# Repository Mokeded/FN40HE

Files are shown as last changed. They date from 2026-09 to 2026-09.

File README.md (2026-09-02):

# FN40HE

FN40HE is a 40%, Hall-effect mechanical keyboard PCB and firmware project. It
adapts the FN40 layout to magnetic (Hall-effect) switches, giving every key
analog actuation — per-key adjustable actuation points, Rapid Trigger,
SOCD/Null Bind, Dynamic Keystroke, and analog gamepad output — instead of a
fixed mechanical trip point.

## What's in this repository

- **KiCad hardware design** — `FN40HE.kicad_pro`/`.kicad_sch`/`.kicad_pcb`,
  a two-layer PCB with 57 independent Hall-sensor channels multiplexed down
  to an 8-channel ADC scan order, plus `FN40HE-plate.step` for the
  mechanical plate reference. `FN40_Project.pretty`, `lib`, `fp-lib-table`,
  and `sym-lib-table` are the local footprint/symbol libraries needed to
  open the project without external dependencies.
- **Firmware** (`firmware/`) — a [libhmk](https://github.com/libhmk/libhmk)-derived
  build configured for the `fn40he` board target, with prebuilt DFU
  artifacts in `firmware/build/` and full source under `firmware/source/`
  for rebuilding.
- **Manufacturing and assembly data** — `FN40HE-BOM.csv` (bill of
  materials for all assembly variants), `FN40HE-ASSEMBLY.md` (which
  mutually-exclusive switch/sensor positions to populate per variant),
  `FN40HE-sensor-map.csv` and `FN40HE-mux-map.csv` (physical-to-firmware
  key mapping), and `manufacturing/FN40HE-Gerbers-JLCPCB.zip` (bare-board
  fab archive).
- **Verification records** — `FN40HE-DRC.rpt` and `FN40HE-ERC.rpt` (PCB/
  schematic check reports) and `FN40HE-J1-WAIVER.md` (documented DRC
  waiver and inspection requirement for the J1 connector footprint).

See `FN40HE-README.md` for release status, build/flash instructions, and
firmware feature details.

## Assembly variants

The board supports three populate/DNP variants sharing one PCB:
**Universal57** (all 57 sensors populated — the released default),
**SplitSpace**, and **SevenUnit** (alternate bottom-row layouts). See
`FN40HE-ASSEMBLY.md` and the DNP columns in `FN40HE-BOM.csv` before
ordering assembly.

## License

This project incorporates GPLv3-derived hardware design and firmware work.
See `LICENSE`. Retain source, license, and attribution when redistributing
modifications.

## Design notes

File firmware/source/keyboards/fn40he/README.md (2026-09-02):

# FN40HE

FN40HE is a 57-position Hall-effect conversion of the Mokeded FN40 PCB. It uses
the HE60 v2 AT32F405 analog architecture and the libhmk firmware stack.

- MCU: AT32F405RCT7
- Oscillator: 12 MHz HSE
- USB: high-speed (`hs`) through the unified daughterboard connector
- Sensors: 57 x MT9102ET
- Multiplexers: 8 x SN74LV4051A
- PCB: 2 layers, 1.2 mm finished thickness

The default key numbering follows `sensor-map.csv`: firmware key 0 is HE1 and
firmware key 56 is HE57. The unused mux slots are encoded as zero, matching
libhmk's convention.

The firmware includes per-key adjustable actuation, split and continuous Rapid
Trigger, Null Bind/SOCD and distance priority, Dynamic Keystroke, tap-hold,
toggle, macros, four onboard profiles, automatic calibration, analog XInput,
and high-speed polling. See [FEATURES.md](FEATURES.md) for configuration details
and safe initial settings. `Fn + F9` swaps profiles and `Fn + F10` selects the
next profile.

Enter the factory AT32 DFU bootloader by holding the physical BOOT button while
connecting USB, or by using the `SP_BOOT` binding on layer 1.

Run `python setup.py -k fn40he`, then `pio run` to build.

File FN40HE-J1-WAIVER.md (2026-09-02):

# J1 mounting-relief DRC waiver

Date: 2026-08-28  
Scope: J1 only — Molex 781710004 unified-daughterboard connector mounting
reliefs.

## Waived findings

The eight annular-width and eight hole-to-hole findings associated with J1's
mounting-relief geometry are waived for this placement-stage revision. They
are intentional features of the project-local
`J1_MOLEX_781710004_MountingReliefs` footprint and do not represent a changed
electrical connection or a routing defect.

The `MP` mounting/relief pad is tied to GND in both the board and schematic.
The J1 position and footprint geometry match the working MX FN40 reference
board used by this project. The electrical pins remain VBUS, D-, D+, and GND.

## Conditions of this waiver

- Use only the specified Molex 781710004 connector and the current local
  footprint geometry.
- Confirm the relief/drill drawing against the selected PCB fabricator's
  capabilities before release.
- Inspect the connector on the first assembled prototype for fit, retention,
  and daughterboard alignment.
- Verify the unified daughterboard cable orientation before applying power.
- This waiver does not cover clearance, shorts, unconnected nets, USB,
  analog, power, mechanical, or any other DRC category.

The imported 4060 DRC policy globally ignores some hole-related categories;
this record preserves the intended, limited engineering rationale for J1.

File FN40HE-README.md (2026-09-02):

# FN40HE release project

This folder is the compact, portable FN40 Hall-effect keyboard project. Open
`FN40HE.kicad_pro` in KiCad 10.

## Release checks completed on 2026-09-01

- PCB DRC: 0 violations, 0 unconnected pads, 0 footprint errors.
- Schematic ERC: 0 errors and 0 warnings.
- Firmware mapping: all 64 mux channels agree across the PCB, schematic,
  `FN40HE-mux-map.csv`, and the firmware configuration.
- ADC order: A3, A4, A5, A6, A7, C4, C5, B0.
- Firmware clean build: successful with compiler warnings treated as errors.
- Firmware size: 33,452 bytes flash (12.8%) and 14,724 bytes RAM (14.1%).
- JLCPCB Gerber ZIP: archive integrity passed.

The firmware is source/build/mapping ready, but it has not yet been proven on
an assembled FN40HE PCB. The first prototype still needs DFU flashing, USB
enumeration, every-key analog verification, calibration, and functional tests
for Rapid Trigger, SOCD, actuation settings, profiles, and alternate layouts.

## Main files

- `FN40HE.kicad_pro`, `FN40HE.kicad_sch`, `FN40HE.kicad_pcb`: KiCad project.
- `FN40_Project.pretty`, `lib`, `fp-lib-table`, `sym-lib-table`: portable local
  footprint and symbol libraries required by the KiCad project.
- `FN40HE-BOM.csv`: assembly bill of materials.
- `FN40HE-ASSEMBLY.md`: mutually exclusive layout/population guidance.
- `FN40HE-sensor-map.csv`, `FN40HE-mux-map.csv`: physical and firmware maps.
- `FN40HE-J1-WAIVER.md`: inherited connector drilling rationale and first-unit
  inspection requirement.
- `FN40HE-DRC.rpt`, `FN40HE-ERC.rpt`: final electrical check reports.
- `FN40HE-plate.step`: plate/mechanical reference.
- `manufacturing/FN40HE-Gerbers-JLCPCB.zip`: current bare-board upload archive.
- `firmware/build/FN40HE.bin`: normal DFU flashing artifact.
- `firmware/build/FN40HE.hex` and `FN40HE.elf`: alternate/debug artifacts.
- `firmware/source`: complete libhmk-derived source for rebuilding.

## Firmware build and flashing

From `firmware/source`, install PlatformIO, then run:

```sh
python setup.py -k fn40he
pio run
```

The checked-in `platformio.ini` is already configured for `fn40he`. Enter the
AT32 factory DFU bootloader by holding BOOT while connecting USB, then flash
`firmware/build/FN40HE.bin` with a compatible AT32/DFU tool. Do not flash the
first production batch before one assembled prototype has passed the hardware
tests listed above.

## Firmware features and configuration

The firmware includes four profiles, per-key adjustable actuation, split and
continuous Rapid Trigger, Null Bind/SOCD and distance priority, Dynamic
Keystroke, macros, analog gamepad mappings, calibration, and high-speed USB
polling. Use hmkconf after flashing and calibration. The default profile starts
with Rapid Trigger and SOCD disabled.

## Manufacturing notes

The intended board is two-layer FR-4, 1.2 mm finished thickness, and 1 oz outer
copper. Review the J1 reliefs and routed NPTH slots in JLCPCB's CAM viewer. The
J1 geometry is inherited from the working MX FN40 and remains a documented
prototype inspection item.

The design and firmware include GPLv3-derived work. Retain `LICENSE`, source,
and attribution when redistributing modifications.

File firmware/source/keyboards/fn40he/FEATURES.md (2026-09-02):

# FN40HE analog and gaming features

The FN40HE firmware uses libhmk's analog input and advanced-key engine. The
settings are stored in the emulated EEPROM on the AT32F405, so the configurator
does not need to stay open after saving a profile.

Use [hmkconf](https://hmkconf.com/) to configure the features below after the
firmware has been flashed and the keyboard has completed its initial
calibration.

## Onboard profiles

The keyboard provides four onboard profiles. Each profile stores its own
keymap, per-key actuation and Rapid Trigger settings, advanced keys, macros,
gamepad bindings, analog curve, and tick rate.

- `Fn + F9`: swap between the default profile and the last non-default profile.
- `Fn + F10`: advance to the next profile.

The default profile starts with Rapid Trigger and SOCD disabled. This avoids
surprising key behavior before the Hall sensors have been tested and calibrated.

The first boot of this feature build resets settings written by the earlier
32-advanced-key FN40 firmware because the persistent profile layout is larger.
Subsequent updates using the same layout preserve the onboard settings normally.

## Adjustable actuation

Every Hall-effect key has an independent actuation point represented internally
as a normalized value from 0 to 255 over its calibrated travel. The default is
128, or approximately the middle of the measured travel. Use the live analog
view in hmkconf to tune actuation after the switches have been installed.

## Rapid Trigger

Rapid Trigger can be enabled per key. Press and release sensitivity can share
one value or use separate values. Continuous mode keeps Rapid Trigger active
until the key returns to its calibrated rest position.

For a first hardware test, begin with a conservative sensitivity and enable it
only on movement keys. Extremely small values can amplify sensor noise or
mechanical wobble, especially before every key has reached bottom-out at least
once and established its travel range.

## SOCD and distance priority

Null Bind pairs provide the following simultaneous-key resolution modes:

- last input wins;
- first/primary key wins;
- second/secondary key wins;
- neutral, where both keys are released;
- distance priority, where the more deeply pressed key wins.

Distance priority is the libhmk equivalent of Wooting's Rappy Snappy behavior.
An optional bottom-out threshold can allow both keys once both have passed that
depth. Typical pairs are `A`/`D` and `W`/`S`.

SOCD rules differ between games and tournaments. Configure the behavior that is
permitted for the intended game rather than assuming last-input or distance
priority is universally allowed.

## Dynamic Keystroke and advanced keys

The firmware reserves 57 advanced-key slots per profile, enough for every
physical Hall-effect key. Supported advanced behaviors include:

- Dynamic Keystroke with up to four bindings and actions at press, bottom-out,
  release from bottom-out, and release;
- tap-hold;
- toggle;
- macros;
- Null Bind/SOCD pairs.

Dynamic Keystroke temporarily controls the affected key's press stages itself,
so the firmware suppresses Rapid Trigger for that key while a DKS stroke is in
progress.

## Analog gamepad

Profiles can map keys to XInput buttons, triggers, or joystick directions. The
analog curve, circular or square joystick output, and snappy opposite-axis
behavior are configurable. XInput is disabled by default so the keyboard starts
as a conventional USB keyboard.

## Calibration and polling

The keyboard automatically calibrates the resting sensor values at startup and
learns each key's bottom-out range during use. A full recalibration is also
available through hmkconf.

High-speed polling is enabled by default for the AT32F405 USB high-speed
interface. The firmware can fall back to the lower polling mode through its
global options if compatibility testing requires it.

## Scope compared with Wooting

These features provide comparable input concepts, but this is not Wooting
firmware and does not use Wootility. Physical travel accuracy depends on the
MT9102ET sensors, magnet/switch geometry, calibration, filtering, and noise of
the assembled FN40HE. RGB lighting is not supported by libhmk.

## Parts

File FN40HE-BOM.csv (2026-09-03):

Item | Value | Package | Manufacturer | Manufacturer_Part_Number | Qty_Universal57 | Qty_SplitSpace | DNP_SplitSpace | Qty_SevenUnit | DNP_SevenUnit | References_Universal57 | Notes
1 | SN74LV4051A | TSSOP-16_4.4x5mm_P0.65mm | Texas Instruments | SN74LV4051APWR | 8 | 8 |  | 8 |  | AM1 AM2 AM3 AM4 AM5 AM6 AM7 AM8 | JLC/LCSC C7793; 8:1 analog mux, TSSOP-16
2 | 100n | C_0402_1005Metric | Samsung Electro-Mechanics | CL05B104KO5NNNC | 70 | 68 | C109 C111 | 65 | C97 C99 C101 C103 C107 | C1 C3 C5 C7 C9 C11 C13 C15 C17 C19 C21 C23 C25 C27 C29 C31 C33 C35 C37 C39 C41 C43 C45 C47 C49 C51 C53 C55 C57 C59 C61 C63 C65 C67 C69 C71 C73 C75 C77 C79 C81 C83 C85 C87 C89 C91 C93 C95 C97 C99 C101 C103 C105 C107 C109 C111 C113 C139 C140 C141 C142 C143 C144 C145 C146 C154 C155 C156 C158 C160 | JLC/LCSC C1525 (Basic part); X7R, 16 V, 10%; package C_0402_1005Metric; reconfirm stock before order
3 | 4.7n | C_0402_1005Metric | Murata | GRM1555C1H472JE01D | 57 | 55 | C110 C112 | 52 | C98 C100 C102 C104 C108 | C2 C4 C6 C8 C10 C12 C14 C16 C18 C20 C22 C24 C26 C28 C30 C32 C34 C36 C38 C40 C42 C44 C46 C48 C50 C52 C54 C56 C58 C60 C62 C64 C66 C68 C70 C72 C74 C76 C78 C80 C82 C84 C86 C88 C90 C92 C94 C96 C98 C100 C102 C104 C106 C108 C110 C112 C114 | JLC/LCSC C1518204; C0G, 50 V, 5%; package C_0402_1005Metric; reconfirm stock before order
4 | 2.2u | C_0603_1608Metric | Murata | GRM188R71A225KE15D | 4 | 4 |  | 4 |  | C148 C149 C150 C151 | JLC/LCSC C86018; X7R, 10 V, 10%; package C_0603_1608Metric; reconfirm stock before order
5 | 30p | C_0603_1608Metric | FH (Guangdong Fenghua) | 0603CG300J500NT | 2 | 2 |  | 2 |  | C152 C153 | JLC/LCSC C1658 (Basic part); C0G, 50 V, 5%; package C_0603_1608Metric; reconfirm stock before order
6 | 10u | C_0603_1608Metric | Yageo | CC0603MRX5R5BB106 | 1 | 1 |  | 1 |  | C157 | JLC/LCSC C109454; X5R, 6.3 V, 20%; package C_0603_1608Metric; reconfirm stock before order
7 | 1u | C_0603_1608Metric | FH (Guangdong Fenghua) | 0603B105K160NT | 1 | 1 |  | 1 |  | C159 | JLC/LCSC C93816; X7R, 16 V, 10%; package C_0603_1608Metric; reconfirm stock before order
8 | BSMD0805-050-24V | Fuse_0805_2012Metric | BHFUSE | BSMD0805-050-24V | 1 | 1 |  | 1 |  | F1 | JLC/LCSC C910822; 0.5 A resettable fuse, 0805; reconfirm stock before order
9 | MT9102ET | MT9102ET / key-center footprint | NOVOSENSE | MT9102ET | 57 | 55 | HE55 HE56 | 52 | HE49 HE50 HE51 HE52 HE54 | HE1 HE2 HE3 HE4 HE5 HE6 HE7 HE8 HE9 HE10 HE11 HE12 HE13 HE14 HE15 HE16 HE17 HE18 HE19 HE20 HE21 HE22 HE23 HE24 HE25 HE26 HE27 HE28 HE29 HE30 HE31 HE32 HE33 HE34 HE35 HE36 HE37 HE38 HE39 HE40 HE41 HE42 HE43 HE44 HE45 HE46 HE47 HE48 HE49 HE50 HE51 HE52 HE53 HE54 HE55 HE56 HE57 | Linear Hall-effect sensor; JLC/LCSC C5447698; verify polarity and switch magnet
10 | Unified_Daughterboard_4P | MOLEX_781710004_MountingReliefs | Molex | 781710004 | 1 | 1 |  | 1 |  | J1 | JLC/LCSC C588524; Pico-EZmate 1.20 mm, 4 circuits; confirm mating cable and footprint drawing
11 | 12k | R_0402_1005Metric | UNI-ROYAL | 0402WGF1202TCE | 2 | 2 |  | 2 |  | R3 R4 | JLC/LCSC C25752 (Basic part); 1%, 1/16 W; package R_0402_1005Metric; reconfirm stock before order
12 | TS-1187A-B-A-B | SW_Push_1P1T_XKB_TS-1187A | XKB Industrial Precision | TS-1187A-B-A-B | 2 | 2 |  | 2 |  | SW1 SW2 | JLC/LCSC C318884; momentary tact switch; reconfirm stock before order
13 | USBLC6-2SC6 | SOT-23-6 | STMicroelectronics | USBLC6-2SC6 | 1 | 1 |  | 1 |  | U1 | JLC/LCSC C7519; USB ESD protection; do not substitute a different manufacturer without review
14 | TLV75733PDBV | SOT-23-5 | Texas Instruments | TLV75733PDBVR | 1 | 1 |  | 1 |  | U2 | JLC/LCSC C485517; 3.3 V LDO, SOT-23-5; reconfirm stock before order
15 | XC6206P332MR-G | SOT-23-3 | Torex Semiconductor | XC6206P332MR-G | 1 | 1 |  | 1 |  | U3 | JLC/LCSC C5446; 3.3 V analog LDO, SOT-23-3; reconfirm stock before order
16 | AT32F405RCT7 | LQFP-64_10x10mm_P0.5mm | Artery Technology | AT32F405RCT7 | 1 | 1 |  | 1 |  | U4 | JLC/LCSC C47090415; 216 MHz MCU, LQFP-64; reconfirm stock before order
17 | X322512MSB4SI | Crystal_SMD_3225-4Pin_3.2x2.5mm | Yangxing Tech | X322512MSB4SI | 1 | 1 |  | 1 |  | Y1 | JLC/LCSC C9002; 12 MHz, 20 pF crystal, 3.2 x 2.5 mm, 4 pad; reconfirm stock before order

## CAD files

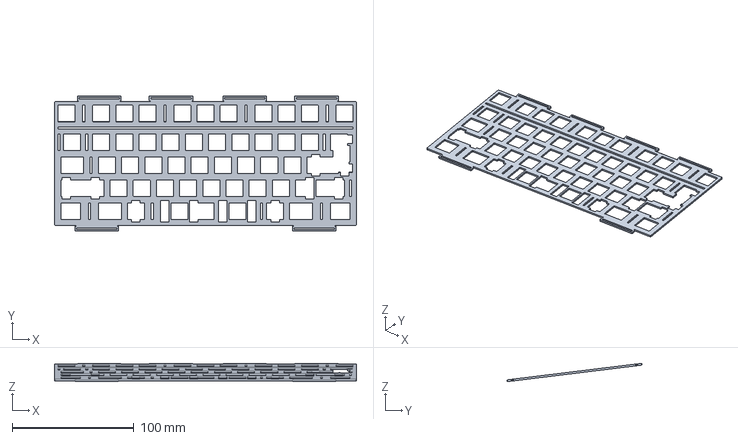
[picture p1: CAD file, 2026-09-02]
FN40HE-plate.step
248.2 x 111.3 x 15.1 mm

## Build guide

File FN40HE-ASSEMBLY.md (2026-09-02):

# Assembly variants

The PCB contains 57 independent Hall-sensor channels. The overlapping bottom
row switch positions are mechanical alternatives; do not install switches or a
plate that attempts to use overlapping options simultaneously.

HE48/HE48A and HE53/HE53A are close alternate-layout pairs. Each pair retains
both switch outlines and both alignment-hole pairs but uses one midpoint Hall
sensor and one capacitor pair, as on HE60. Do not add a second sensor at the
mechanical-only HE48A or HE53A position.

## Universal57 — selected release variant

Populate all PCB components, including all 57 MT9102ET sensors and their local
filter capacitors. Select the physical switch layout with the plate. Unused
sensors remain available for a later layout change. This is the default BOM and
the supplied 57-key firmware configuration. The 2026-08-28 prototype release
package uses this variant; SplitSpace and SevenUnit remain documented future
assembly alternatives and are not the released population set.

## SplitSpace

Use the primary split-space bottom row. Do not populate:

- HE55 / C109 / C110 — alternate SW50 position
- HE56 / C111 / C112 — alternate 7U SW53 position

All other components are populated. Firmware for a permanently assembled
SplitSpace board should replace the two omitted mux entries with zero or ignore
firmware keys 54 and 55.

## SevenUnit

Use the original KLE alternative positions SW50 and SW53. Do not populate the
sensors and filter pairs under primary keys that conflict with the 7U keycap:

- HE49 / C97 / C98 — SW51
- HE50 / C99 / C100 — SW52
- HE51 / C101 / C102 — SW54
- HE52 / C103 / C104 — SW55
- HE54 / C107 / C108 — SW49

Populate HE55 (SW50), HE56 (SW53), and HE57 (SW56). The plate, stabilizer
locations, and keycap clearances must be checked against the original FN40 KLE
before ordering. Firmware for a permanently assembled SevenUnit board should
replace the five omitted mux entries with zero or ignore their firmware keys.

`BOM.csv` contains quantities and DNP reference columns for all three variants.

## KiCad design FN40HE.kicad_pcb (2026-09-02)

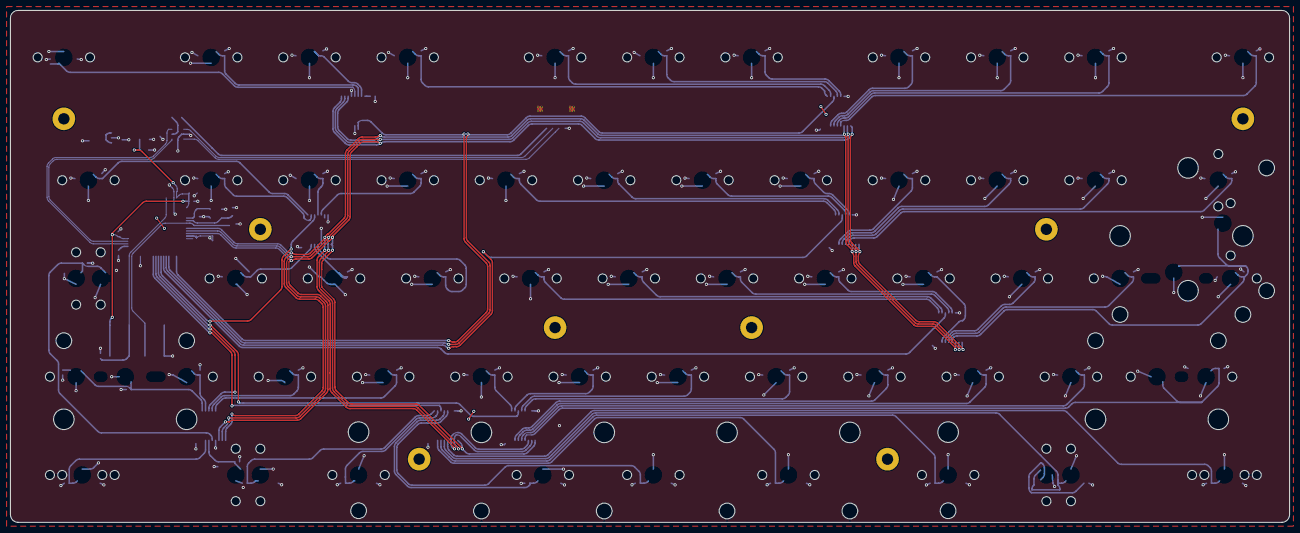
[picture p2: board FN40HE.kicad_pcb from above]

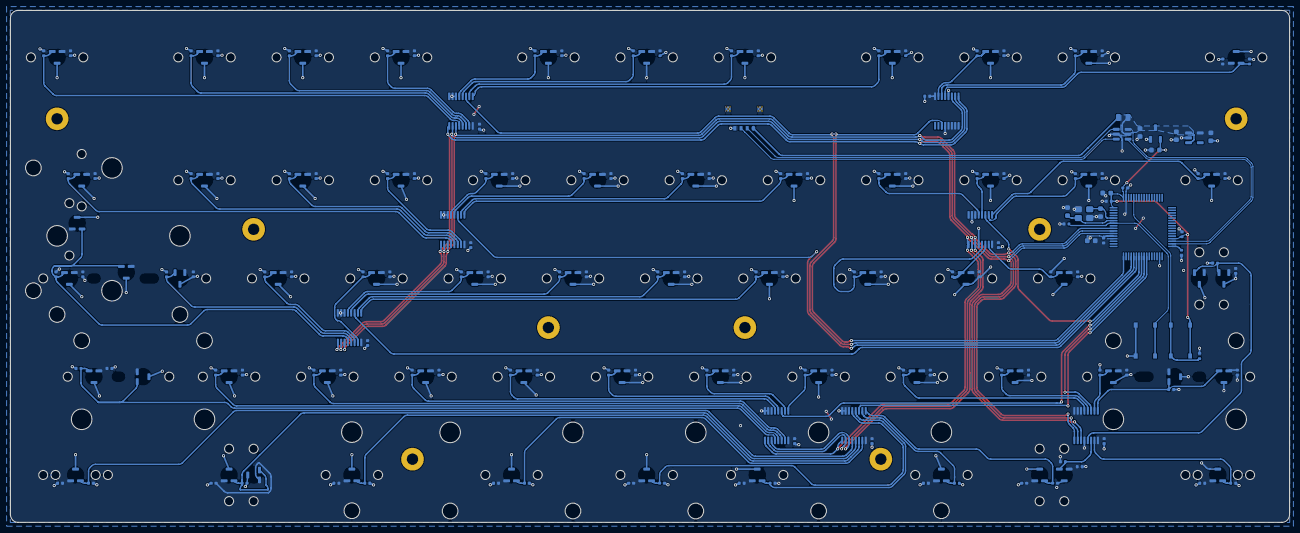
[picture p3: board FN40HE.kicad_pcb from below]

Board: 2 copper layers, 248.0 x 99.2 mm, 234 parts (219 on the bottom side), 82 nets.

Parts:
AM1: SN74LV4051A; AM1_TSSOP-16_4.4x5mm_P0.65mm
AM2: SN74LV4051A; AM2_TSSOP-16_4.4x5mm_P0.65mm
AM3: SN74LV4051A; AM3_TSSOP-16_4.4x5mm_P0.65mm
AM4: SN74LV4051A; AM4_TSSOP-16_4.4x5mm_P0.65mm
AM5: SN74LV4051A; AM5_TSSOP-16_4.4x5mm_P0.65mm
AM6: SN74LV4051A; AM6_TSSOP-16_4.4x5mm_P0.65mm
AM7: SN74LV4051A; AM7_TSSOP-16_4.4x5mm_P0.65mm
AM8: SN74LV4051A; AM8_TSSOP-16_4.4x5mm_P0.65mm
C1: 100n; C1_C_0402_1005Metric
C2: 4.7n; C2_C_0402_1005Metric
C3: 100n; C3_C_0402_1005Metric
C4: 4.7n; C4_C_0402_1005Metric
C5: 100n; C5_C_0402_1005Metric
C6: 4.7n; C6_C_0402_1005Metric
C7: 100n; C7_C_0402_1005Metric
C8: 4.7n; C8_C_0402_1005Metric
C9: 100n; C9_C_0402_1005Metric
C10: 4.7n; C10_C_0402_1005Metric
C11: 100n; C11_C_0402_1005Metric
C12: 4.7n; C12_C_0402_1005Metric
C13: 100n; C13_C_0402_1005Metric
C14: 4.7n; C14_C_0402_1005Metric
C15: 100n; C15_C_0402_1005Metric
C16: 4.7n; C16_C_0402_1005Metric
C17: 100n; C17_C_0402_1005Metric
C18: 4.7n; C18_C_0402_1005Metric
C19: 100n; C19_C_0402_1005Metric
C20: 4.7n; C20_C_0402_1005Metric
C21: 100n; C21_C_0402_1005Metric
C22: 4.7n; C22_C_0402_1005Metric
C23: 100n; C23_C_0402_1005Metric
C24: 4.7n; C24_C_0402_1005Metric
C25: 100n; C25_C_0402_1005Metric
C26: 4.7n; C26_C_0402_1005Metric
C27: 100n; C27_C_0402_1005Metric
C28: 4.7n; C28_C_0402_1005Metric
C29: 100n; C29_C_0402_1005Metric
C30: 4.7n; C30_C_0402_1005Metric
C31: 100n; C31_C_0402_1005Metric
C32: 4.7n; C32_C_0402_1005Metric
C33: 100n; C33_C_0402_1005Metric
C34: 4.7n; C34_C_0402_1005Metric
C35: 100n; C35_C_0402_1005Metric
C36: 4.7n; C36_C_0402_1005Metric
C37: 100n; C37_C_0402_1005Metric
C38: 4.7n; C38_C_0402_1005Metric
C39: 100n; C39_C_0402_1005Metric
C40: 4.7n; C40_C_0402_1005Metric
C41: 100n; C41_C_0402_1005Metric
C42: 4.7n; C42_C_0402_1005Metric
C43: 100n; C43_C_0402_1005Metric
C44: 4.7n; C44_C_0402_1005Metric
C45: 100n; C45_C_0402_1005Metric
C46: 4.7n; C46_C_0402_1005Metric
C47: 100n; C47_C_0402_1005Metric
C48: 4.7n; C48_C_0402_1005Metric
C49: 100n; C49_C_0402_1005Metric
C50: 4.7n; C50_C_0402_1005Metric
C51: 100n; C51_C_0402_1005Metric
C52: 4.7n; C52_C_0402_1005Metric
C53: 100n; C53_C_0402_1005Metric
C54: 4.7n; C54_C_0402_1005Metric
C55: 100n; C55_C_0402_1005Metric
C56: 4.7n; C56_C_0402_1005Metric
C57: 100n; C57_C_0402_1005Metric
C58: 4.7n; C58_C_0402_1005Metric
C59: 100n; C59_C_0402_1005Metric
C60: 4.7n; C60_C_0402_1005Metric
C61: 100n; C61_C_0402_1005Metric
C62: 4.7n; C62_C_0402_1005Metric
C63: 100n; C63_C_0402_1005Metric
C64: 4.7n; C64_C_0402_1005Metric
C65: 100n; C65_C_0402_1005Metric
C66: 4.7n; C66_C_0402_1005Metric
C67: 100n; C67_C_0402_1005Metric
C68: 4.7n; C68_C_0402_1005Metric
C69: 100n; C69_C_0402_1005Metric
C70: 4.7n; C70_C_0402_1005Metric
C71: 100n; C71_C_0402_1005Metric
C72: 4.7n; C72_C_0402_1005Metric
C73: 100n; C73_C_0402_1005Metric
C74: 4.7n; C74_C_0402_1005Metric
C75: 100n; C75_C_0402_1005Metric
C76: 4.7n; C76_C_0402_1005Metric
C77: 100n; C77_C_0402_1005Metric
C78: 4.7n; C78_C_0402_1005Metric
C79: 100n; C79_C_0402_1005Metric
C80: 4.7n; C80_C_0402_1005Metric
C81: 100n; C81_C_0402_1005Metric
C82: 4.7n; C82_C_0402_1005Metric
C83: 100n; C83_C_0402_1005Metric
C84: 4.7n; C84_C_0402_1005Metric
C85: 100n; C85_C_0402_1005Metric
C86: 4.7n; C86_C_0402_1005Metric
C87: 100n; C87_C_0402_1005Metric
C88: 4.7n; C88_C_0402_1005Metric
C89: 100n; C89_C_0402_1005Metric
C90: 4.7n; C90_C_0402_1005Metric
C91: 100n; C91_C_0402_1005Metric
C92: 4.7n; C92_C_0402_1005Metric
C93: 100n; C93_C_0402_1005Metric
C94: 4.7n; C94_C_0402_1005Metric
C95: 100n; C95_C_0402_1005Metric
C96: 4.7n; C96_C_0402_1005Metric
C97: 100n; C97_C_0402_1005Metric
C98: 4.7n; C98_C_0402_1005Metric
C99: 100n; C99_C_0402_1005Metric
C100: 4.7n; C100_C_0402_1005Metric
C101: 100n; C101_C_0402_1005Metric
C102: 4.7n; C102_C_0402_1005Metric
C103: 100n; C103_C_0402_1005Metric
C104: 4.7n; C104_C_0402_1005Metric
C105: 100n; C105_C_0402_1005Metric
C106: 4.7n; C106_C_0402_1005Metric
C107: 100n; C107_C_0402_1005Metric
C108: 4.7n; C108_C_0402_1005Metric
C109: 100n; C109_C_0402_1005Metric
C110: 4.7n; C110_C_0402_1005Metric
C111: 100n; C111_C_0402_1005Metric
C112: 4.7n; C112_C_0402_1005Metric
C113: 100n; C113_C_0402_1005Metric
C114: 4.7n; C114_C_0402_1005Metric
C139: 100n; C139_C_0402_1005Metric
C140: 100n; C140_C_0402_1005Metric
C141: 100n; C141_C_0402_1005Metric
C142: 100n; C142_C_0402_1005Metric
C143: 100n; C143_C_0402_1005Metric
C144: 100n; C144_C_0402_1005Metric
C145: 100n; C145_C_0402_1005Metric
C146: 100n; C146_C_0402_1005Metric
C148: 2.2u; C148_C_0603_1608Metric
C149: 2.2u; C149_C_0603_1608Metric
C150: 2.2u; C150_C_0603_1608Metric
C151: 2.2u; C151_C_0603_1608Metric
C152: 30p; C152_C_0603_1608Metric
C153: 30p; C153_C_0603_1608Metric
C154: 100n; C154_C_0402_1005Metric
C155: 100n; C155_C_0402_1005Metric
C156: 100n; C156_C_0402_1005Metric
C157: 10u; C157_C_0603_1608Metric
C158: 100n; C158_C_0402_1005Metric
C159: 1u; C159_C_0603_1608Metric
C160: 100n; C160_C_0402_1005Metric
F1: BSMD0805-050-24V; F1_Fuse_0805_2012Metric
HE1: MT9102ET; HE1_MT9102ET_Key_1.00u
HE2: MT9102ET; HE2_MT9102ET_Key_1.00u
HE3: MT9102ET; HE3_MT9102ET_Key_1.00u
HE4: MT9102ET; HE4_MT9102ET_Key_1.00u
HE5: MT9102ET; HE5_MT9102ET_Key_1.00u
HE6: MT9102ET; HE6_MT9102ET_Key_1.00u
HE7: MT9102ET; HE7_MT9102ET_Key_1.00u
HE8: MT9102ET; HE8_MT9102ET_Key_1.00u
HE9: MT9102ET; HE9_MT9102ET_Key_1.00u
HE10: MT9102ET; HE10_MT9102ET_Key_1.00u
HE11: MT9102ET; HE11_MT9102ET_Key_1.00u
HE12: MT9102ET; HE12_MT9102ET_Key_1.50u
HE13: MT9102ET; HE13_MT9102ET_Key_1.00u
HE14: MT9102ET; HE14_MT9102ET_Key_1.00u
HE15: MT9102ET; HE15_MT9102ET_Key_1.00u
HE16: MT9102ET; HE16_MT9102ET_Key_1.00u
HE17: MT9102ET; HE17_MT9102ET_Key_1.00u
HE18: MT9102ET; HE18_MT9102ET_Key_1.00u
HE19: MT9102ET; HE19_MT9102ET_Key_1.00u
HE20: MT9102ET; HE20_MT9102ET_Key_1.00u
HE21: MT9102ET; HE21_MT9102ET_Key_1.00u
HE22: MT9102ET; HE22_MT9102ET_Key_1.00u
HE23: MT9102ET; HE23_MT9102ET_Key_1.50u
HE24: MT9102ET; HE24_MT9102ET_Key_1.75u_90deg
HE24A: MT9102ET_ALT_SW24_1_DNP; HE24A_MT9102ET_KLE_SW24_1
HE25: MT9102ET; HE25_MT9102ET_Key_1.00u
HE26: MT9102ET; HE26_MT9102ET_Key_1.00u
HE27: MT9102ET; HE27_MT9102ET_Key_1.00u
HE28: MT9102ET; HE28_MT9102ET_Key_1.00u
HE29: MT9102ET; HE29_MT9102ET_Key_1.00u
HE30: MT9102ET; HE30_MT9102ET_Key_1.00u
HE31: MT9102ET; HE31_MT9102ET_Key_1.00u
HE32: MT9102ET; HE32_MT9102ET_Key_1.00u
HE33: MT9102ET; HE33_MT9102ET_Key_1.00u
HE34: MT9102ET; HE34_MT9102ET_Key_1.00u
HE35: MT9102ET; HE35_MT9102ET_Key_1.25u
HE35A: MT9102ET_ALT_SW35_1_DNP; HE35A_MT9102ET_KLE_SW35_1
HE35B: MT9102ET_ALT_SW35_2_DNP; HE35B_MT9102ET_KLE_SW35_2
HE36: MT9102ET; HE36_MT9102ET_Key_1.25u
HE36A: MT9102ET_ALT_SW36_1_DNP; HE36A_MT9102ET_KLE_SW36_1
HE37: MT9102ET; HE37_MT9102ET_Key_1.00u
HE38: MT9102ET; HE38_MT9102ET_Key_1.00u
HE39: MT9102ET; HE39_MT9102ET_Key_1.00u
HE40: MT9102ET; HE40_MT9102ET_Key_1.00u
HE41: MT9102ET; HE41_MT9102ET_Key_1.00u
HE42: MT9102ET; HE42_MT9102ET_Key_1.00u
HE43: MT9102ET; HE43_MT9102ET_Key_1.00u
HE44: MT9102ET; HE44_MT9102ET_Key_1.00u
HE45: MT9102ET; HE45_MT9102ET_Key_1.00u
HE46: MT9102ET; HE46_MT9102ET_Key_1.00u
HE47: MT9102ET; HE47_MT9102ET_Key_1.75u
HE47A: MT9102ET_ALT_SW47_1_DNP; HE47A_MT9102ET_KLE_SW47_1
HE48: MT9102ET; HE48_MT9102ET_Key_1.50u
HE48A: MECHANICAL_ALT_SHARED_SENSOR_DNP; HE48A_MECHANICAL_ALT
HE49: MT9102ET; HE49_MT9102ET_Key_1.00u
HE50: MT9102ET; HE50_MT9102ET_Key_2.75u
HE51: MT9102ET; HE51_MT9102ET_Key_2.25u
HE52: MT9102ET; HE52_MT9102ET_Key_1.00u
HE53: MT9102ET; HE53_MT9102ET_Key_1.50u
HE53A: MECHANICAL_ALT_SHARED_SENSOR_DNP; HE53A_MECHANICAL_ALT
HE54: MT9102ET; HE54_MT9102ET_Key_1.50u
HE55: MT9102ET; HE55_MT9102ET_Key_1.00u
HE56: MT9102ET; HE56_MT9102ET_Key_7.00u
HE57: MT9102ET; HE57_MT9102ET_Key_1.50u
HE57A: MT9102ET_ALT_SW56_1_DNP; HE57A_MT9102ET_KLE_SW56_1
J1: Unified_Daughterboard_4P; J1_MOLEX_781710004_MountingReliefs
MH1, MH2, MH3, MH4, MH5, MH6, MH7, MH8: M2_PLATE_STANDOFF; MountingHole_2.2mm_M2_Pad
R3: 12k; R3_R_0402_1005Metric
R4: 12k; R4_R_0402_1005Metric
S1: FN40_PCB_STABILIZER_HOLES; S1_STABILIZER_HOLES
S2: FN40_PCB_STABILIZER_HOLES; S2_STABILIZER_HOLES
S3: FN40_PCB_STABILIZER_HOLES; S3_STABILIZER_HOLES
S4: FN40_PCB_STABILIZER_HOLES; S4_STABILIZER_HOLES
S5: FN40_PCB_STABILIZER_HOLES; S5_STABILIZER_HOLES
S6: FN40_PCB_STABILIZER_HOLES; S6_STABILIZER_HOLES
S7: FN40_PCB_STABILIZER_HOLES; S7_STABILIZER_HOLES
SW1: TS-1187A-B-A-B; SW1_SW_Push_1P1T_XKB_TS-1187A
SW2: TS-1187A-B-A-B; SW2_SW_Push_1P1T_XKB_TS-1187A
U1: USBLC6-2SC6; U1_SOT-23-6
U2: TLV75733PDBV; U2_SOT-23-5
U3: XC6206P332MR-G; U3_SOT-23-3
U4: AT32F405RCT7; U4_LQFP-64_10x10mm_P0.5mm
Y1: X322512MSB4SI; Y1_Crystal_SMD_3225-4Pin_3.2x2.5mm

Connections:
+3.3V: C151.1, C154.1, C155.1, C156.1, C157.1, SW2.2, U3.2 (VO), U4.1 (VDD), U4.36 (VDD), U4.64 (VDD)
+3.3VA: AM1.16 (VDD), AM2.16 (VDD), AM3.16 (VDD), AM4.16 (VDD), AM5.16 (VDD), AM6.16 (VDD), AM7.16 (VDD), AM8.16 (VDD), C1.1, C3.1, C5.1, C7.1, C9.1, C11.1, C13.1, C15.1, C17.1, C19.1, C21.1, C23.1, C25.1, C27.1, C29.1, C31.1, C33.1, C35.1, C37.1, C39.1, C41.1, C43.1, C45.1, C47.1, C49.1, C51.1, C53.1, C55.1, C57.1, C59.1, C61.1, C63.1, C65.1, C67.1, C69.1, C71.1, C73.1, C75.1, C77.1, C79.1, C81.1, C83.1, C85.1, C87.1, C89.1, C91.1, C93.1, C95.1, C97.1, C99.1, C101.1, C103.1, C105.1, C107.1, C109.1, C111.1, C113.1, C139.1, C140.1, C141.1, C142.1, C143.1, C144.1, C145.1, C146.1, C149.1, C158.1, C159.1, HE1.1 (VCC), HE2.1 (VCC), HE3.1 (VCC), HE4.1 (VCC), HE5.1 (VCC), HE6.1 (VCC), HE7.1 (VCC), HE8.1 (VCC), HE9.1 (VCC), HE10.1 (VCC), HE11.1 (VCC), HE12.1 (VCC), HE13.1 (VCC), HE14.1 (VCC), HE15.1 (VCC), HE16.1 (VCC), HE17.1 (VCC), HE18.1 (VCC), HE19.1 (VCC), HE20.1 (VCC), HE21.1 (VCC), HE22.1 (VCC), HE23.1 (VCC), HE24.1 (VCC), HE24A.1 (VCC), HE25.1 (VCC), HE26.1 (VCC), HE27.1 (VCC), HE28.1 (VCC), HE29.1 (VCC), HE30.1 (VCC), HE31.1 (VCC), HE32.1 (VCC), HE33.1 (VCC), HE34.1 (VCC), HE35.1 (VCC), HE35A.1 (VCC), HE35B.1 (VCC), HE36.1 (VCC), HE36A.1 (VCC), HE37.1 (VCC), HE38.1 (VCC), HE39.1 (VCC), HE40.1 (VCC), HE41.1 (VCC), HE42.1 (VCC), HE43.1 (VCC), HE44.1 (VCC), HE45.1 (VCC), HE46.1 (VCC), HE47.1 (VCC), HE47A.1 (VCC), HE48.1 (VCC), HE49.1 (VCC), HE50.1 (VCC), HE51.1 (VCC), HE52.1 (VCC), HE53.1 (VCC), HE54.1 (VCC), HE55.1 (VCC), HE56.1 (VCC), HE57.1 (VCC), HE57A.1 (VCC), U2.5 (OUT), U4.13 (VDDA)
+5V: C148.1, C150.1, F1.2, U1.5 (VBUS), U2.1 (IN), U2.3 (EN), U3.3 (VI)
BOOT0: R4.1, SW2.1, U4.60 (PF11/BOOT0)
GND: AM1.4 (X7), AM1.5 (X5), AM1.6 (Inh), AM1.7 (VEE), AM1.8 (VSS), AM1.12 (X3), AM2.6 (Inh), AM2.7 (VEE), AM2.8 (VSS), AM3.6 (Inh), AM3.7 (VEE), AM3.8 (VSS), AM4.6 (Inh), AM4.7 (VEE), AM4.8 (VSS), AM5.6 (Inh), AM5.7 (VEE), AM5.8 (VSS), AM5.12 (X3), AM6.6 (Inh), AM6.7 (VEE), AM6.8 (VSS), AM7.6 (Inh), AM7.7 (VEE), AM7.8 (VSS), AM7.12 (X3), AM8.6 (Inh), AM8.7 (VEE), AM8.8 (VSS), C1.2, C2.2, C3.2, C4.2, C5.2, C6.2, C7.2, C8.2, C9.2, C10.2, C11.2, C12.2, C13.2, C14.2, C15.2, C16.2, C17.2, C18.2, C19.2, C20.2, C21.2, C22.2, C23.2, C24.2, C25.2, C26.2, C27.2, C28.2, C29.2, C30.2, C31.2, C32.2, C33.2, C34.2, C35.2, C36.2, C37.2, C38.2, C39.2, C40.2, C41.2, C42.2, C43.2, C44.2, C45.2, C46.2, C47.2, C48.2, C49.2, C50.2, C51.2, C52.2, C53.2, C54.2, C55.2, C56.2, C57.2, C58.2, C59.2, C60.2, C61.2, C62.2, C63.2, C64.2, C65.2, C66.2, C67.2, C68.2, C69.2, C70.2, C71.2, C72.2, C73.2, C74.2, C75.2, C76.2, C77.2, C78.2, C79.2, C80.2, C81.2, C82.2, C83.2, C84.2, C85.2, C86.2, C87.2, C88.2, C89.2, C90.2, C91.2, C92.2, C93.2, C94.2, C95.2, C96.2, C97.2, C98.2, C99.2, C100.2, C101.2, C102.2, C103.2, C104.2, C105.2, C106.2, C107.2, C108.2, C109.2, C110.2, C111.2, C112.2, C113.2, C114.2, C139.2, C140.2, C141.2, C142.2, C143.2, C144.2, C145.2, C146.2, C148.2, C149.2, C150.2, C151.2, C152.2, C153.2, C154.2, C155.2, C156.2, C157.2, C158.2, C159.2, C160.2, HE1.3 (GND), HE2.3 (GND), HE3.3 (GND), HE4.3 (GND), HE5.3 (GND), HE6.3 (GND), HE7.3 (GND), HE8.3 (GND), HE9.3 (GND), HE10.3 (GND), HE11.3 (GND), HE12.3 (GND), HE13.3 (GND), HE14.3 (GND), HE15.3 (GND), HE16.3 (GND), HE17.3 (GND), HE18.3 (GND), HE19.3 (GND), HE20.3 (GND), HE21.3 (GND), HE22.3 (GND), HE23.3 (GND), HE24.3 (GND), HE24A.3 (GND), HE25.3 (GND), HE26.3 (GND), HE27.3 (GND), HE28.3 (GND), HE29.3 (GND), HE30.3 (GND), HE31.3 (GND), HE32.3 (GND), HE33.3 (GND), HE34.3 (GND), HE35.3 (GND), HE35A.3 (GND), HE35B.3 (GND), HE36.3 (GND), HE36A.3 (GND), HE37.3 (GND), HE38.3 (GND), HE39.3 (GND), HE40.3 (GND), HE41.3 (GND), HE42.3 (GND), HE43.3 (GND), HE44.3 (GND), HE45.3 (GND), HE46.3 (GND), HE47.3 (GND), HE47A.3 (GND), HE48.3 (GND), HE49.3 (GND), HE50.3 (GND), HE51.3 (GND), HE52.3 (GND), HE53.3 (GND), HE54.3 (GND), HE55.3 (GND), HE56.3 (GND), HE57.3 (GND), HE57A.3 (GND), J1.4, J1.MP (MountPin), R3.1, R4.2, SW1.2, U1.2 (GND), U2.2 (GND), U3.1 (GND), U4.12 (VSSA), U4.31 (VSS), U4.63 (VSS), Y1.2, Y1.4
HE1: AM1.13 (X0), C2.1, HE1.2 (OUT)
HE2: AM1.14 (X1), C4.1, HE2.2 (OUT)
HE3: AM1.15 (X2), C6.1, HE3.2 (OUT)
HE4: AM2.1 (X4), C8.1, HE4.2 (OUT)
HE5: AM2.2 (X6), C10.1, HE5.2 (OUT)
HE6: AM2.4 (X7), C12.1, HE6.2 (OUT)
HE7: AM2.5 (X5), C14.1, HE7.2 (OUT)
HE8: AM2.15 (X2), C16.1, HE8.2 (OUT)
HE9: AM2.14 (X1), C18.1, HE9.2 (OUT)
HE10: AM2.13 (X0), C20.1, HE10.2 (OUT)
HE11: AM2.12 (X3), C22.1, HE11.2 (OUT)
HE12: AM5.1 (X4), C24.1, HE12.2 (OUT)
HE13: AM5.2 (X6), C26.1, HE13.2 (OUT)
HE14: AM5.4 (X7), C28.1, HE14.2 (OUT)
HE15: AM5.5 (X5), C30.1, HE15.2 (OUT)
HE16: AM3.1 (X4), C32.1, HE16.2 (OUT)
HE17: AM3.2 (X6), C34.1, HE17.2 (OUT)
HE18: AM3.4 (X7), C36.1, HE18.2 (OUT)
HE19: AM3.5 (X5), C38.1, HE19.2 (OUT)
HE20: AM3.15 (X2), C40.1, HE20.2 (OUT)
HE21: AM3.14 (X1), C42.1, HE21.2 (OUT)
HE22: AM3.13 (X0), C44.1, HE22.2 (OUT)
HE23: AM3.12 (X3), C46.1, HE23.2 (OUT)
HE24: AM7.13 (X0), C48.1, HE24.2 (OUT), HE24A.2 (OUT)
HE25: AM5.15 (X2), C50.1, HE25.2 (OUT)
HE26: AM5.14 (X1), C52.1, HE26.2 (OUT)
HE27: AM5.13 (X0), C54.1, HE27.2 (OUT)
HE28: AM4.1 (X4), C56.1, HE28.2 (OUT)
HE29: AM4.2 (X6), C58.1, HE29.2 (OUT)
HE30: AM4.4 (X7), C60.1, HE30.2 (OUT)
HE31: AM4.5 (X5), C62.1, HE31.2 (OUT)
HE32: AM4.15 (X2), C64.1, HE32.2 (OUT)
HE33: AM4.14 (X1), C66.1, HE33.2 (OUT)
HE34: AM4.13 (X0), C68.1, HE34.2 (OUT)
HE35: AM4.12 (X3), C70.1, HE35.2 (OUT), HE35A.2 (OUT), HE35B.2 (OUT)
HE36: AM7.1 (X4), C72.1, HE36.2 (OUT), HE36A.2 (OUT)
HE37: AM7.2 (X6), C74.1, HE37.2 (OUT)
HE38: AM7.4 (X7), C76.1, HE38.2 (OUT)
HE39: AM7.5 (X5), C78.1, HE39.2 (OUT)
HE40: AM6.1 (X4), C80.1, HE40.2 (OUT)
HE41: AM6.2 (X6), C82.1, HE41.2 (OUT)
HE42: AM6.4 (X7), C84.1, HE42.2 (OUT)
HE43: AM6.5 (X5), C86.1, HE43.2 (OUT)
HE44: AM6.15 (X2), C88.1, HE44.2 (OUT)
HE45: AM6.14 (X1), C90.1, HE45.2 (OUT)
HE46: AM6.13 (X0), C92.1, HE46.2 (OUT)
HE47: AM6.12 (X3), C94.1, HE47.2 (OUT), HE47A.2 (OUT)
HE48: AM7.15 (X2), C96.1, HE48.2 (OUT)
HE49: AM8.2 (X6), C98.1, HE49.2 (OUT)
HE50: AM8.4 (X7), C100.1, HE50.2 (OUT)
HE51: AM8.15 (X2), C102.1, HE51.2 (OUT)
HE52: AM8.14 (X1), C104.1, HE52.2 (OUT)
HE53: AM8.12 (X3), C106.1, HE53.2 (OUT)
HE54: AM7.14 (X1), C108.1, HE54.2 (OUT)
HE55: AM8.1 (X4), C110.1, HE55.2 (OUT)
HE56: AM8.5 (X5), C112.1, HE56.2 (OUT)
HE57: AM8.13 (X0), C114.1, HE57.2 (OUT), HE57A.2 (OUT)
HEXT_IN: C152.1, U4.5 (PF0/HEXT_IN), Y1.1
HEXT_OUT: C153.1, U4.6 (PF1/HEXT_OUT), Y1.3
MUX_OUT_1: AM1.3 (X), U4.17 (PA3)
MUX_OUT_2: AM2.3 (X), U4.20 (PA4)
MUX_OUT_3: AM3.3 (X), U4.21 (PA5)
MUX_OUT_4: AM4.3 (X), U4.22 (PA6)
MUX_OUT_5: AM5.3 (X), U4.23 (PA7)
MUX_OUT_6: AM6.3 (X), U4.24 (PC4)
MUX_OUT_7: AM7.3 (X), U4.25 (PC5)
MUX_OUT_8: AM8.3 (X), U4.26 (PB0)
MUX_SELECT_0: AM1.11 (A), AM2.11 (A), AM3.11 (A), AM4.11 (A), AM5.11 (A), AM6.11 (A), AM7.9 (C), AM8.11 (A), U4.9 (PC1)
MUX_SELECT_1: AM1.10 (B), AM2.10 (B), AM3.10 (B), AM4.10 (B), AM5.10 (B), AM6.10 (B), AM7.10 (B), AM8.10 (B), U4.10 (PC2)
MUX_SELECT_2: AM1.9 (C), AM2.9 (C), AM3.9 (C), AM4.9 (C), AM5.9 (C), AM6.9 (C), AM7.11 (A), AM8.9 (C), U4.11 (PC3)
NRST: C160.1, SW1.1, U4.7 (NRST)
unnamed: R3.2, U4.33 (OTGHS1_R)
USB_D+: U1.4 (I/O2), U4.35 (OTGHS1_D+)
USB_D-: U1.6 (I/O1), U4.34 (OTGHS1_D-)
USB_PLUG_D+: J1.3, U1.3 (I/O2)
USB_PLUG_D-: J1.2, U1.1 (I/O1)
VBUS: F1.1, J1.1

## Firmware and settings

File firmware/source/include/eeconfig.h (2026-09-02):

/*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
 * You should have received a copy of the GNU General Public License along with
 * this program. If not, see <https://www.gnu.org/licenses/>.
 */

#pragma once

#include "common.h"
#include "wear_leveling.h"

//--------------------------------------------------------------------+
// Keyboard Persistent Configuration
//--------------------------------------------------------------------+

// Magic number to identify the start of the configuration
#if !defined(EECONFIG_MAGIC_START)
#define EECONFIG_MAGIC_START 0x0A42494C
#endif
// Magic number to identify the end of the configuration
#define EECONFIG_MAGIC_END 0x0A4B4D48

// Keyboard calibration configuration
typedef struct __attribute__((packed)) {
  // Initial rest value of the key matrix. If the value is smaller than the
  // actual rest value, the key will have a dead zone at the beginning of the
  // keystroke. If the value is larger than the actual rest value, a longer
  // calibration process may be required.
  uint16_t initial_rest_value;
  // Minimum change in ADC values for the key to be considered bottom-out. If
  // the value is larger than the actual bottom-out threshold, the key will have
  // a dead zone at the end of the keystroke. If the value is smaller than the
  // actual bottom-out threshold, the distance calculation may be inaccurate
  // until the first bottom-out event.
  uint16_t initial_bottom_out_threshold;
} eeconfig_calibration_t;

// Keyboard options configuration
typedef union __attribute__((packed)) {
  struct __attribute__((packed)) {
    // Whether the XInput interface is enabled
    bool xinput_enabled : 1;
    bool _unused0 : 1;
    // Whether 8kHz polling rate is enabled. Only applicable if USB HS is
    // enabled. If disabled, the 1kHz polling rate is used instead.
    bool high_polling_rate_enabled : 1;
    // Reserved bits for future use
    uint16_t reserved : 13;
  };
  uint16_t raw;
} eeconfig_options_t;

_Static_assert(sizeof(eeconfig_options_t) == sizeof(uint16_t),
               "Invalid eeconfig_options_t size");

// Keyboard profile configuration
typedef struct __attribute__((packed)) {
  uint8_t keymap[NUM_LAYERS][NUM_KEYS];
  actuation_t actuation_map[NUM_KEYS];
  advanced_key_t advanced_keys[NUM_ADVANCED_KEYS];
  macro_node_t macros[NUM_MACRO_NODES];
  uint8_t gamepad_buttons[NUM_KEYS];
  gamepad_options_t gamepad_options;
  uint8_t tick_rate;
} eeconfig_profile_t;

// Persistent configuration version. The size of the configuration must be
// non-decreasing, so that the migration can assume that the new version is at
// least as large as the previous version.
#define EECONFIG_VERSION 0x0105

// Keyboard configuration
// Whenever there is a change in the configuration, `EECONFIG_VERSION` must be
// bumped. Make sure to update `eeconfig_reset()`, and add a migration function
// in `migration.c`.
typedef struct __attribute__((packed)) {
  // Global configurations
  // Magic number to identify the start of the configuration
  uint32_t magic_start;
  // Version of the configuration
  uint16_t version;

  // Calibration configuration
  eeconfig_calibration_t calibration;
  // Saved bottom-out threshold
  uint16_t bottom_out_threshold[NUM_KEYS];
  // Options configuration
  eeconfig_options_t options;

  // Current profile index
  uint8_t current_profile;
  // Last non-default profile index, used for profile swapping
  uint8_t last_non_default_profile;
  // End of global configurations

  // Profiles
  eeconfig_profile_t profiles[NUM_PROFILES];

  // Magic number to identify the end of the configuration
  uint32_t magic_end;
} eeconfig_t;

_Static_assert(
    sizeof(eeconfig_t) <= WL_VIRTUAL_SIZE,
    "Keyboard configuration size must be at most the virtual storage size.");

extern const eeconfig_t *eeconfig;

#define CURRENT_PROFILE (eeconfig->profiles[eeconfig->current_profile])

//--------------------------------------------------------------------+
// Default Keyboard Configuration
//--------------------------------------------------------------------+

#if !defined(DEFAULT_CALIBRATION)
#error "DEFAULT_CALIBRATION is not defined"
#endif

#if !defined(DEFAULT_OPTIONS)
// Default global options
#define DEFAULT_OPTIONS                                                        \
  {                                                                            \
      .xinput_enabled = false,                                                 \
      .high_polling_rate_enabled = true,                                       \
  }
#endif

#if !defined(DEFAULT_KEYMAPS)
#error "DEFAULT_KEYMAPS is not defined"
#endif

#if !defined(DEFAULT_ACTUATION_POINT)
// Default actuation point
#define DEFAULT_ACTUATION_POINT 128
#endif

#if !defined(DEFAULT_GAMEPAD_OPTIONS)
// Default gamepad options
#define DEFAULT_GAMEPAD_OPTIONS                                                \
  {                                                                            \
      .analog_curve = {{4, 20}, {85, 95}, {165, 170}, {255, 255}},             \
      .keyboard_enabled = true,                                                \
      .snappy_joystick = true,                                                 \
  }
#endif

#if !defined(DEFAULT_TICK_RATE)
// Default tick rate
#define DEFAULT_TICK_RATE 30
#endif

//--------------------------------------------------------------------+
// Persistent Configuration API
//--------------------------------------------------------------------+

/**
 * @brief Initialize the persistent configuration module
 *
 * @return None
 */
void eeconfig_init(void);

/**
 * @brief Reset the persistent configuration to default values
 *
 * @return true if successful, false otherwise
 */
bool eeconfig_reset(void);

/**
 * @brief Reset a specific profile to default values
 *
 * @param profile Profile index
 *
 * @return true if successful, false otherwise
 */
bool eeconfig_reset_profile(uint8_t profile);

/**
 * @brief Write a value to a field in the persistent configuration
 *
 * @param field Field to write to
 * @param value Value to write
 *
 * @return true if successful, false otherwise
 */
#define EECONFIG_WRITE(field, value)                                           \
  wear_leveling_write(offsetof(eeconfig_t, field), value,                      \
                      sizeof(((eeconfig_t *)0)->field))

/**
 * @brief Write a value to a field in the persistent configuration
 *
 * @param field Field to write to
 * @param value Value to write
 * @param len Length of the value in bytes
 *
 * @return true if successful, false otherwise
 */
#define EECONFIG_WRITE_N(field, value, len)                                    \
  wear_leveling_write(offsetof(eeconfig_t, field), value, len)

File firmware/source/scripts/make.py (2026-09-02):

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
import utils
from drivers import *
from schema.keyboard import KeyboardUSBPort

Import("env")

keyboard = env["PIOENV"]

# Load JSON files and driver. We assume that they have been validated in `get_deps.py`.
kb_json = utils.get_kb_json(keyboard)
driver = utils.get_driver(keyboard)
driver_name = kb_json.hardware.driver

# Add source filter for driver source files
env.Append(
    SRC_FILTER=[
        "-<hardware/>",
        f"+<hardware/{driver_name}/>",
        "-<**/._*>",
    ]
)

# Build Flags
build_flags = utils.CompilerFlags()

# Include headers. We prioritize including driver and keyboard headers.
build_flags.include(f"hardware/{driver_name}")
build_flags.include(f"keyboards/{keyboard}")
build_flags.include("include")

# Bootloader Configuration
build_flags.define("BOOTLOADER_ADDR", driver.metadata.bootloader.address)
build_flags.define("BOOTLOADER_MAGIC", driver.metadata.bootloader.magic)

# Flash Configuration
flash_size = driver.metadata.flash.get_flash_size()
flash_num_sectors = driver.metadata.flash.get_num_sectors()
build_flags.define("FLASH_SIZE", flash_size)
build_flags.linker_defsym("FLASH_SIZE", flash_size)
build_flags.define("FLASH_NUM_SECTORS", flash_num_sectors)
build_flags.define("FLASH_EMPTY_VAL", driver.metadata.flash.empty_value)

match driver.metadata.flash.sector_sizes:
    case NonUniformSectors(sizes):
        build_flags.define("FLASH_SECTOR_SIZES", utils.to_c_array(sizes))
    case UniformSectors(size, _):
        build_flags.define("FLASH_SECTOR_SIZE", size)

# TinyUSB Configuration
build_flags.define("CFG_TUSB_MCU", f"OPT_MCU_{driver.tinyusb.mcu.upper()}")

# Clock Configuration
build_flags.define("BOARD_HSE_VALUE", kb_json.hardware.hse_value)
build_flags.define("HSE_VALUE", kb_json.hardware.hse_value)

# USB Configuration
if kb_json.usb.port == KeyboardUSBPort.FULL_SPEED:
    build_flags.define("BOARD_USB_FS")
else:
    build_flags.define("BOARD_USB_HS")
build_flags.define("USB_MANUFACTURER_NAME", f'"{kb_json.manufacturer}"')
build_flags.define("USB_PRODUCT_NAME", f'"{kb_json.name}"')
build_flags.define("USB_VENDOR_ID", kb_json.usb.vid)
build_flags.define("USB_PRODUCT_ID", kb_json.usb.pid)

# Analog Configuration
build_flags.define("ADC_NUM_CHANNELS", len(driver.metadata.adc.input_pins))
build_flags.define("ADC_RESOLUTION", utils.get_adc_resolution(kb_json, driver))

if kb_json.analog.invert_adc:
    build_flags.define("MATRIX_INVERT_ADC_VALUES")

if kb_json.analog.delay is not None:
    build_flags.define("ADC_SAMPLE_DELAY", kb_json.analog.delay)

# Raw ADC Input Configuration
if kb_json.analog.raw is not None:
    raw = kb_json.analog.raw

    build_flags.define("ADC_NUM_RAW_INPUTS", len(raw.input))
    build_flags.define(
        "ADC_RAW_INPUT_CHANNELS",
        utils.to_c_array(driver.metadata.adc.to_adc_inputs(raw.input)),
    )
    build_flags.define("ADC_RAW_INPUT_VECTOR", utils.to_c_array(raw.vector))

# Analog Multiplexer ADC Input Configuration
if kb_json.analog.mux is not None:
    mux = kb_json.analog.mux

    build_flags.define("ADC_NUM_MUX_INPUTS", len(mux.input))
    build_flags.define(
        "ADC_MUX_INPUT_CHANNELS",
        utils.to_c_array(driver.metadata.adc.to_adc_inputs(mux.input)),
    )
    build_flags.define("ADC_NUM_MUX_SELECT_PINS", len(mux.select))

    ports, pin_nums = driver.metadata.adc.to_gpio_array(mux.select)
    build_flags.define("ADC_MUX_SELECT_PORTS", utils.to_c_array(ports))
    build_flags.define("ADC_MUX_SELECT_PINS", utils.to_c_array(pin_nums))

    build_flags.define(
        "ADC_MUX_INPUT_MATRIX", utils.to_c_array(list(map(list, zip(*mux.matrix))))
    )

# Calibration Configuration
build_flags.define(
    "DEFAULT_CALIBRATION", utils.to_c_struct(kb_json.calibration.model_dump())
)

# Wear leveling configuration
wear_leveling = kb_json.wear_leveling
wl_virtual_size = (wear_leveling and wear_leveling.virtual_size) or 8192
wl_write_log_size = (wear_leveling and wear_leveling.write_log_size) or 65536
wl_backing_store_size = wl_virtual_size + wl_write_log_size

build_flags.define("WL_VIRTUAL_SIZE", wl_virtual_size)
build_flags.define("WL_WRITE_LOG_SIZE", wl_write_log_size)

# Reserve flash for wear leveling (round up to whole sectors from the end)
wl_base_address = flash_size - driver.metadata.flash.round_up_to_flash_sectors(
    wl_backing_store_size
)
build_flags.define("WL_BASE_ADDRESS", wl_base_address)
build_flags.linker_defsym("WL_BASE_ADDRESS", wl_base_address)

# Keyboard Configuration
kb = kb_json.keyboard
build_flags.define("NUM_PROFILES", kb.num_profiles)
build_flags.define("NUM_LAYERS", kb.num_layers)
build_flags.define("NUM_KEYS", kb.num_keys)
build_flags.define("NUM_ADVANCED_KEYS", kb.num_advanced_keys)
build_flags.define(
    "NUM_DYNAMIC_KEYSTROKE_MAX_BINDINGS", kb.num_dynamic_keystroke_max_bindings
)
build_flags.define("NUM_MACRO_NODES", kb.num_macro_nodes)

# Default Keymaps (per profile)
default_keymaps = utils.resolve_default_keymaps(kb_json)
build_flags.define("DEFAULT_KEYMAPS", utils.to_c_array(default_keymaps))

# Actuation Configuration
if kb_json.actuation is not None:
    actuation = kb_json.actuation
    if actuation.actuation_point is not None:
        build_flags.define("ACTUATION_POINT", actuation.actuation_point)

# Add source build flags
env.Append(BUILD_FLAGS=build_flags.get_flags())

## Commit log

2026-09-02 Initial commit: FN40-HE60 hall-effect keyboard PCB
    60% hall-effect keyboard: 57 MT9102ET sensors read through eight
    SN74LV4051A analog multiplexers into an AT32F405RCT7 MCU.
    Contents:
    - KiCad 9 project: schematic, 2-layer PCB, and project-local
    footprint/symbol libraries (portable via ${KIPRJMOD})
    - manufacturing/: JLCPCB gerber + drill package
    - firmware/: libhmk-derived source and compiled bin/elf/hex
    - Sensor and mux channel maps, BOM, assembly notes, J1 DRC waiver
    - FN40HE-plate.step: switch plate model
    Verified: DRC 0 violations, 0 unconnected pads; ERC 0 errors.
    Derived from the HE60 project; GPLv3 retained.
    [FN40HE-BOM.csv, FN40HE-mux-map.csv, FN40HE-plate.step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]
2026-09-02 Add root README describing the FN40HE project
    Provides a repo-homepage overview (hardware, firmware, manufacturing
    data, assembly variants) alongside the existing detailed FN40HE-README.md.
    Claude-Session: https://claude.ai/code/session_01Au6cUiuN5hphL22LEzFVL9
2026-09-03 Add JLCPCB-ready BOM and CPL files
    Adds assembly files in JLCPCB's expected upload format, generated from
    the board via kicad-cli and verified against it:
    - FN40HE-BOM-JLCPCB.csv: grouped BOM with an "LCSC Part #" column so
    JLCPCB auto-matches parts. 17 lines covering all 211 placed
    designators, including all 57 hall sensors (HE1-HE57).
    - FN40HE-CPL-JLCPCB.csv: position file with JLCPCB column names
    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
    [FN40HE-BOM-JLCPCB.csv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]
2026-09-03 Swap in Basic-library parts and sync master BOM
    Verified every LCSC part in the JLCPCB BOM against JLCPCB's live parts
    library (package, spec, library type, stock, price). All 17 existed with
    matching packages and sufficient stock. Three lines improved:
    - 100nF 0402 (x70): C60474 -> C1525 (CL05B104KO5NNNC). Identical spec
    (100nF 16V X7R +/-10% 0402) at the same price, but a Basic-library
    part with 34.6M stock instead of Extended.
    - 12k 0402 (x2): C114760 -> C25752 (0402WGF1202TCE). Same 12k +/-1%
    0402 at the same price, Basic instead of Extended.
    - 1uF 0603 (x1): C97888 -> C93816 (0603B105K160NT). Same X7R +/-10%
    0603, voltage rating up from 10V to 16V, $0.2110 -> $0.0136, and
    sto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
    [FN40HE-BOM-JLCPCB.csv, FN40HE-BOM.csv]
2026-09-03 Add PCBWay-format BOM and fix two manufacturer fields
    PCBWay's turn-key assembly BOM is MPN-driven rather than keyed on a
    distributor part number, and asks for columns the JLCPCB BOM does not
    carry. Adds FN40HE-BOM-PCBWAY.csv with their requested fields:
    Line#, Quantity, Reference Designator, Part Number, Part Description,
    Package, Type, Manufacturer Name, Manufacturer Part Number,
    Distributor Part Number
    17 lines, 211 placements, designator set verified identical to the CPL
    and the JLCPCB BOM. Type is SMT on every line (all 211 placed
    footprints carry the smd attribute; no through-hole parts). Package uses
    human-readable values confirmed against the parts library rather than
    KiCad f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
    [FN40HE-BOM-PCBWAY.csv, FN40HE-BOM.csv]

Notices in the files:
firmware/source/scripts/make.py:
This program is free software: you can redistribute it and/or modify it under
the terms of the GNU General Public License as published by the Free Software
